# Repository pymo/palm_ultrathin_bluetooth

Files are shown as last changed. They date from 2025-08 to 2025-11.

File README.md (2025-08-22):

# Palm Ultra-thin Keyboard (P10900U) Bluetooth Mod

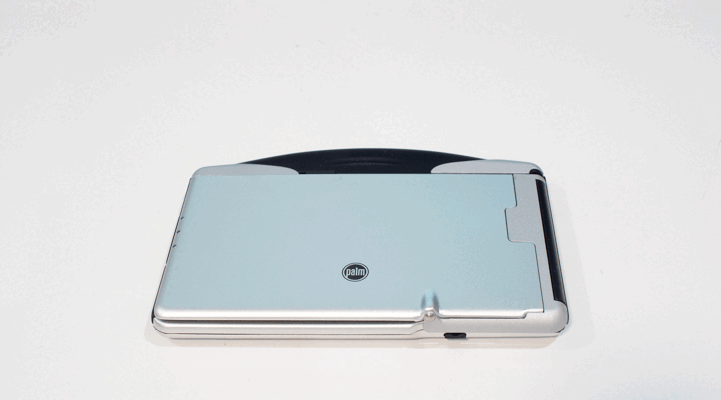
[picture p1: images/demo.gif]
Demo of Palm Ultra-thin keyboard


This project modifies the Palm Ultra-thin Keyboard into a Bluetooth keyboard. The conversion kit includes a custom PCB that replaces the original one, a li-po battery, and a 3D printed cover with power switch. The Bluetooth PCB supports BLE 5.3, can pair up to 4 hosts simultaneously, and supports wired USB Type-C connection.

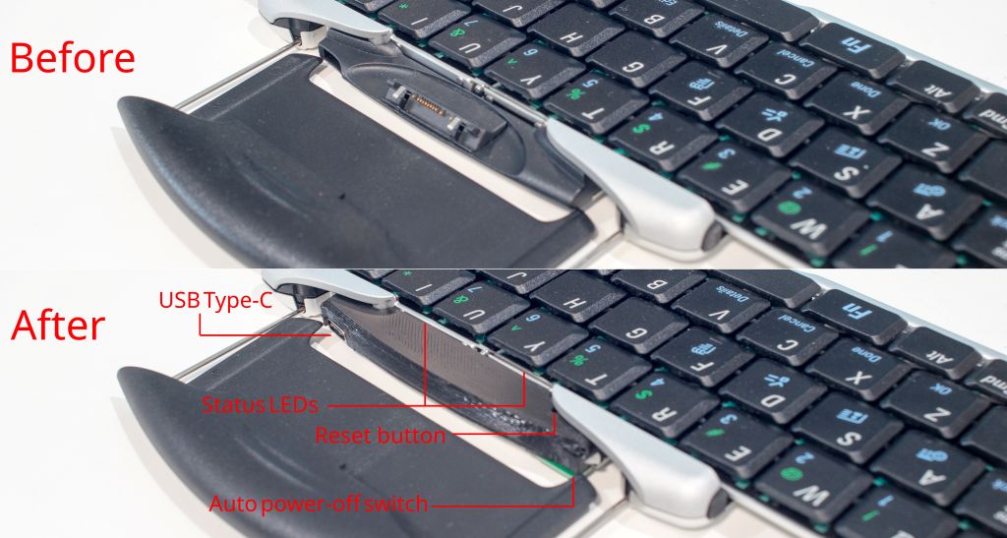
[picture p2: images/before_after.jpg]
Before and after the mod


Where to buy
-----------

You can buy the kit from my [Tindie store](https://www.tindie.com/products/39633/). You can also make the PCB by yourself if you are familiar with PCB making and SMT. The PCB files are in the `/pcb` folder.

Instructions to install the PCB
-----------

[Tutorial for installing the PCB into the keyboard](install.md)

Keyboard Matrix
-----------

[Keyboard matrix table](matrix.md).

PCB design and firmware
-----------
The PCB uses a WCH CH582F chip, a RISC-V based Bluetooth controller. It is low cost, power efficient and easy enough to use, which is why I chose it. The PCB files are at the /pcb folder.

The firmware is in the release page. Follow [this tutorial](https://github.com/pymo/wch_micro_kbd/blob/main/doc/wch_isp_tool.md) to flash the firmware. The source code is in a [separate repo](https://github.com/pymo/wch_micro_kbd/).

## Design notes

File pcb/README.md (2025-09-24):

# Other components used

- switch:  model No. KFC-V-204F or MS-V-204F.
- switch and battery connector: SH 1.0 2-pin
- battery: 401225 Li-Po battery 130mAh (4mm x 12mm x 25mm in dimensions).

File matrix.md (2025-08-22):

# Palm Ultra-thin Keyboard matrix

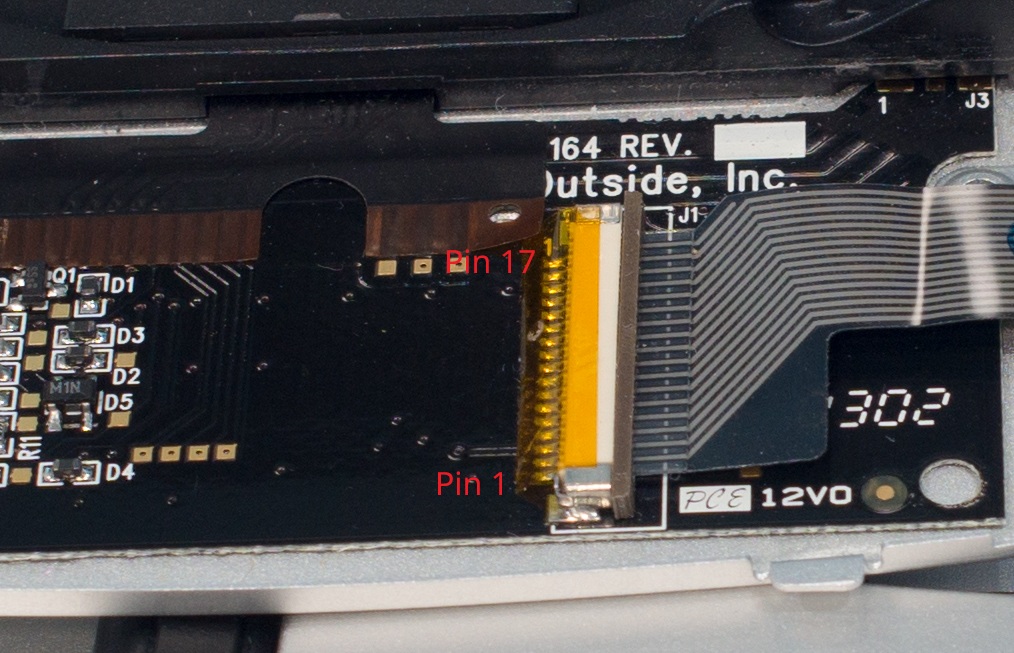
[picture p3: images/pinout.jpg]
Connector pinout


Pin 17 is not used.

| Pin No. | 3 | 4 | 9 | 10 | 14 |
| :---: | :---: | :---: | :---: | :---: | :---: |
| 1 | Up | M | U | Down | K |
| 2 | Left | N | Right Fn | Right Space | J |
| 5 | Return | BS | P | / | = |
| 6 | . | ' | O | Del | - |
| 7 | , | ; | I | Right | L |
| 8 |  |  |  | Right Shift | |
| 11 | V | B | F | C | Left Alt |
| 12 | Caps Lock | Left Ctrl | D | X | T |
| 13 | H | G | Left Fn | Left Space | Y |
| 15 | Q | W | A | Left Shift | E |
| 16 | Cmd | Tab | S | Z | R |

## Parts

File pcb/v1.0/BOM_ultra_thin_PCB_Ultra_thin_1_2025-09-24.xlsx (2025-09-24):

No. | Quantity | Comment | Designator | Footprint | Value | Manufacturer Part | Manufacturer | Supplier Part | Supplier | JLCPCB Price | JLCPCB Stock
1 | 2 | YTC-A1001WF-02A | BATTERY_CONNECTOR,SWITCH_CONNECTOR | CONN-SMD_YTC-A1001WF-02A |  | YTC-A1001WF-02A | YIYUAN(怡远) | C7433423 | LCSC | 0.152 | 31643
2 | 1 | K2-1809SN-A4DW-06 | BOOT | KEY-SMD_4P-L3.5-W3.0-P1.50-LS4.6 |  | K2-1809SN-A4DW-06 | 韩国韩荣 | C223823 | LCSC | 0.657 | 2435
3 | 3 | 2.2uF | C1,C4,C8 | C0603 | 2.2uF | CL10A225KO8NNNC | SAMSUNG(三星) | C23630 | LCSC | 0.0397 | 1952639
4 | 2 | 100nF | C2,C11 | C0402 | 100nF | CL05B104KO5NNNC | SAMSUNG(三星) | C1525 | LCSC | 0.0076 | 11288985
5 | 2 | 1uF | C3,C7 | c0402 | 1uF | CL05A105KA5NQNC | SAMSUNG(三星) | C52923 | LCSC | 0.019 | 5187096
6 | 2 | 10uF | C9,C10 | C0603 | 10uF | CL10A106MA8NRNC | SAMSUNG(三星) | C96446 | LCSC | 0.12 | 2235026
7 | 1 | CH582F | CH582F | qfn-28_l4.0-w4.0-p0.40-bl-ep2.8 |  | CH582F | WCH(南京沁恒) | C3001175 | LCSC | 7.84 | 2060
8 | 1 | 1N5819WS | D2 | SOD-323_L1.8-W1.3-LS2.5-RD |  | 1N5819WS | Hottech(合科泰) | C191023 | LCSC | 0.0632 | 2884036
9 | 1 | ESDR0502NMUTBG | D3 | UDFN-6_L1.2-W1.0-P0.40-BL |  | ESDR0502NMUTBG | onsemi(安森美) | C327480 | LCSC | 1.087 | 2893
10 | 1 | X10B25L17T | FPC1 | FPC-SMD_X10B25U17T |  | X10B25L17T | XKB Connection(中国星坤) | C500176 | LCSC | 0.904 | 2042
11 | 1 | 22uH | L1 | IND-SMD_L2.0-W1.6_NR201610 | 22uH | YNR2016-220M | YJYCOIN(益嘉源) | C2858408 | LCSC | 0.382 | 2259
12 | 1 | LTST-C171TBKT | LED_BLUE | LED0805-RD_BLUE |  | LTST-C171TBKT | LITEON(光宝) | C98225 | LCSC | 0.145 | 28461
13 | 1 | KT-0805G | LED_GREEN | LED0805-R-RD |  | KT-0805G | KENTO | C2297 | LCSC | 0.0714 | 1329987
14 | 1 | NCD0805R1 | LED_RED | LED0805-R-RD |  | NCD0805R1 | 国星光电 | C84256 | LCSC | 0.0879 | 5070270
15 | 1 | KT-0805Y | LED_YELLOW | LED0805-R-RD |  | KT-0805Y | KENTO | C2296 | LCSC | 0.0835 | 266228
16 | 1 | AO3401A | Q2 | SOT-23_L2.9-W1.3-P1.90-LS2.4-BR |  | AO3401A | AOS | C15127 | LCSC | 0.385 | 2428201
17 | 5 | 5.1kΩ | R1,R2,R12,R27,R28 | R0402 | 5.1kΩ | 0402WGF5101TCE | UNI-ROYAL(厚声) | C25905 | LCSC | 0.0031 | 4872753
18 | 4 | 820Ω | R3,R14,R15,R18 | R0603 | 820Ω | 0603WAF8200T5E | UNI-ROYAL(厚声) | C23253 | LCSC | 0.0068 | 228711
19 | 6 | 1MΩ | R16,R19,R20,R21,R22,R23 | R0805 | 1MΩ | 0805W8F1004T5E | UNI-ROYAL(厚声) | C17514 | LCSC | 0.0123 | 593756
20 | 2 | 74HC138T | U1,U2 | TSSOP-16_L5.0-W4.4-P0.65-LS6.4-BL |  | 74HC138T | FM(富满) | C2906781 | LCSC | 0.551 | 1444
21 | 1 | ME6214C33M5G | U5 | SOT-23-5_L3.0-W1.7-P0.95-LS2.8-BL |  | ME6214C33M5G | MICRONE(南京微盟) | C76500 | LCSC | 0.516 | 28205
22 | 1 | TP4054-42-SOT25R | U7 | SOT-23-5_L3.0-W1.7-P0.95-LS2.8-BL |  | TP4054-42-SOT25R | TOPPOWER(南京拓微) | C32574 | LCSC | 0.853 | 8536
23 | 1 | TYPE-C 16PQT 073 | U11 | USB-SMD_TYPE-C-16PQT-073 |  | TYPE-C 16PQT 073 | SHOU HAN(首韩) | C5156603 | LCSC | 0.541 | 3691
24 | 1 | 32MHz | X1 | OSC-SMD_4P-L2.0-W1.6-BL | 32MHz | X201632MMB4SI | YXC(扬兴晶振) | C383840 | LCSC | 0.649 | 2369

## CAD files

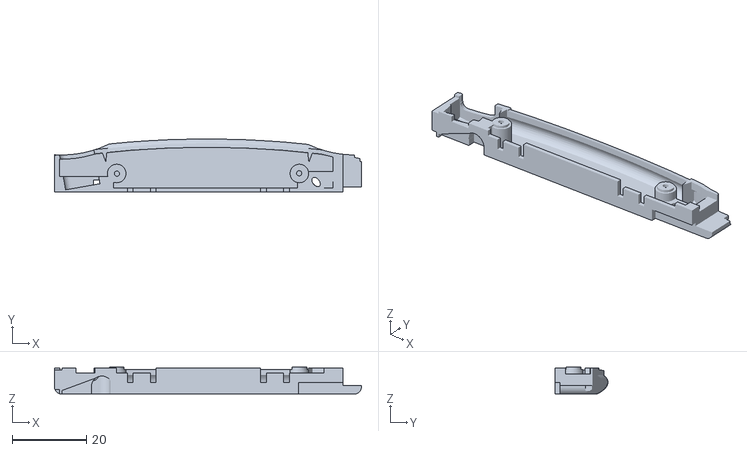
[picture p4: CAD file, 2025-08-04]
3d_print/cover.stl
82.7 x 14.3 x 7.20

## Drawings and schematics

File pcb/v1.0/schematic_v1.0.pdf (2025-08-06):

# 图页EP 29

# PB22/BOOT GND

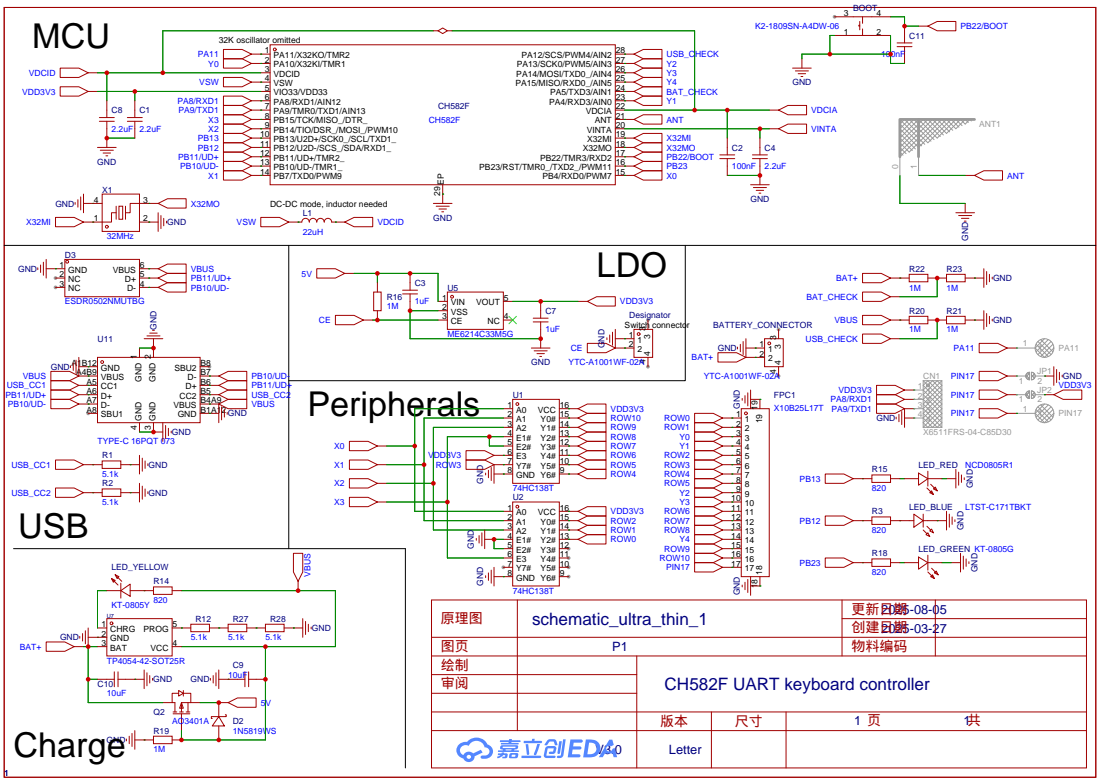
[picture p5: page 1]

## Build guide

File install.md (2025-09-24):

# How to install the Bluetooth conversion kit for Palm Ultra-thin Keyboard

Unscrew the 4 screws at the back of the keyboard.

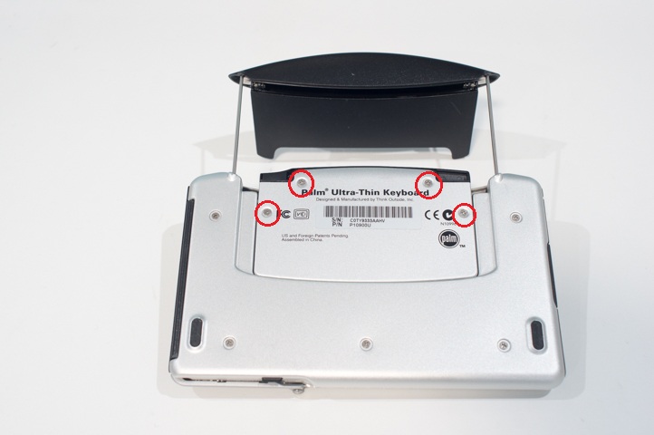
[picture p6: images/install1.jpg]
install pic


Flip the back cover, release the FPC cable by pulling out the "drawer" of the connector.

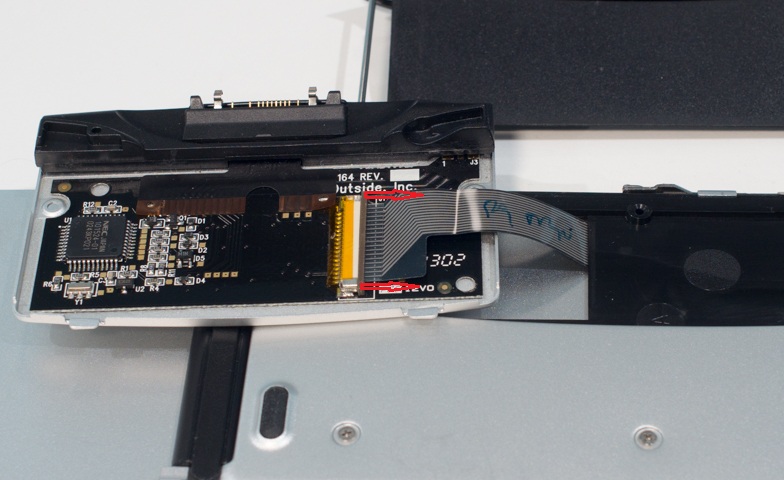
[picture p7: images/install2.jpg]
install pic


Use a prying tool to pry between the PCB and the metal back cover, start from the top left corner. Be careful not to cut yourself with the sharp edges of the tool or the back cover. Be careful not to bend the back cover.

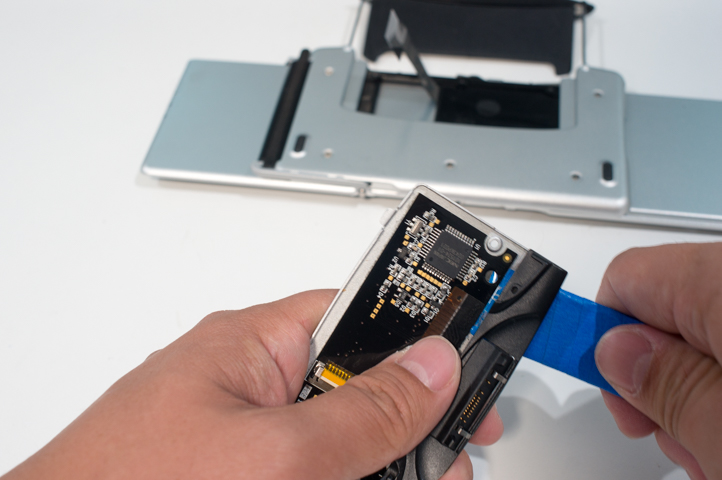
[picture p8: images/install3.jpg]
install pic


Once the PCB comes off, peel any remaining double sided tape off the back cover. If there are any adhesive remaining, it's fine, it can help the new PCB to stick to the back cover.

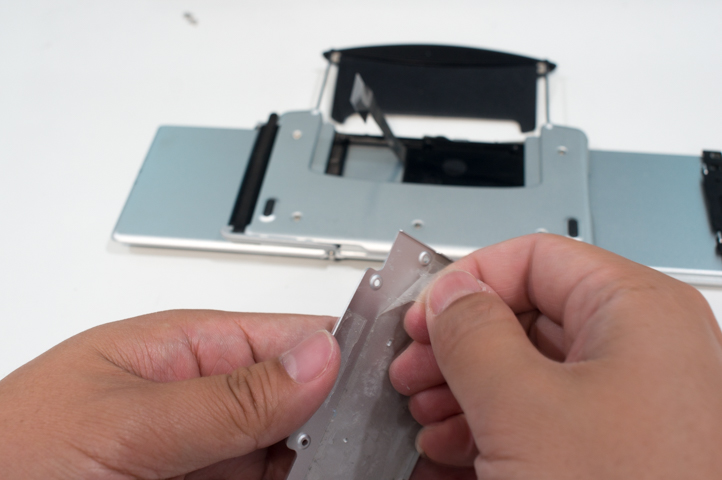
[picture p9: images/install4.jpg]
install pic


Put the new PCB on the back cover. Try to align the screw holes as well as possible.

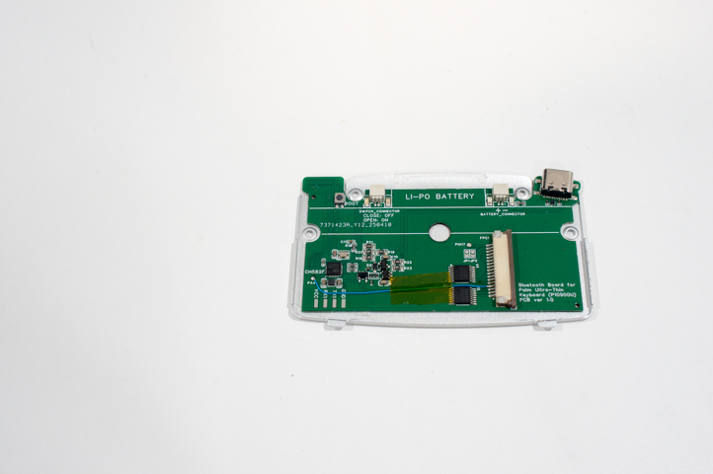
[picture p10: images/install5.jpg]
install pic


Plug in the battery and the power switch, make sure the polarity is correct! The positive (red wire) should be on the left side when looking from top, as marked on the PCB too.

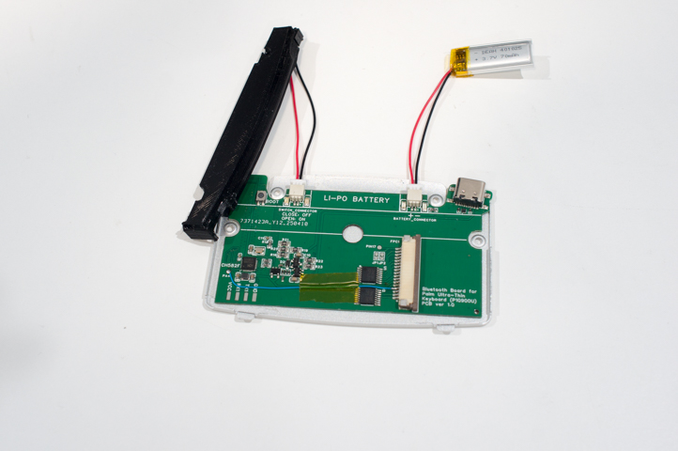
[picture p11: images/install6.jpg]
install pic


Use double sided tape to tape the battery into place, and tuck the wires on the battery.

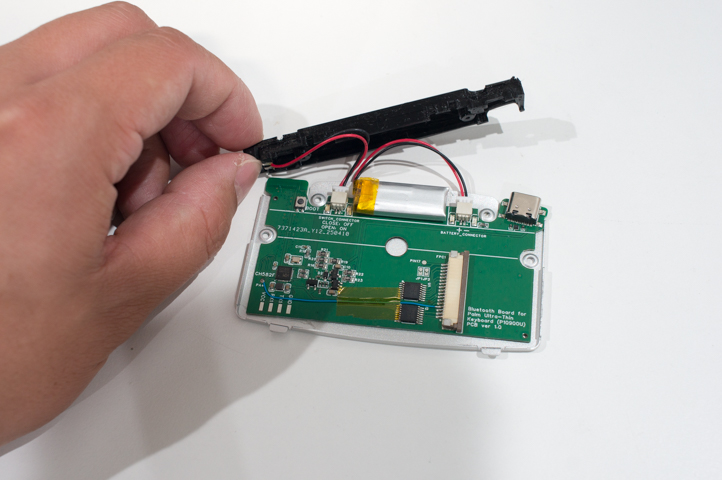
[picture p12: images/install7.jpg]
install pic


Place the 3-D printed cover on the battery. The wires should be tucked inside the cover.

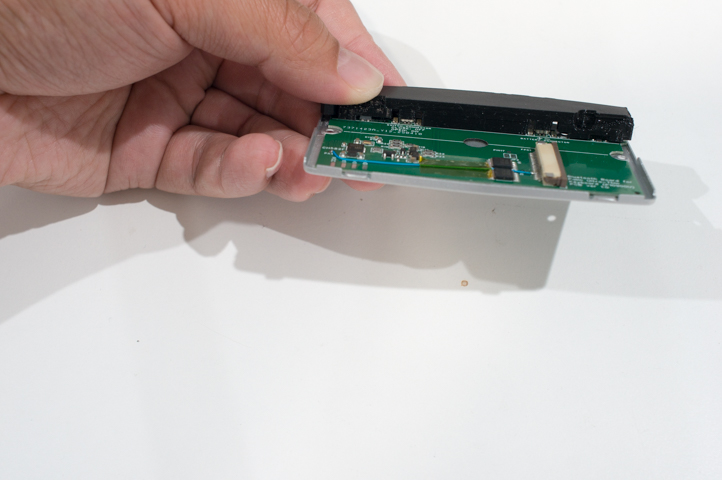
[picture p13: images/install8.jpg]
install pic


Use the two shorter screws to fasten the back cover with the 3-D printed cover.

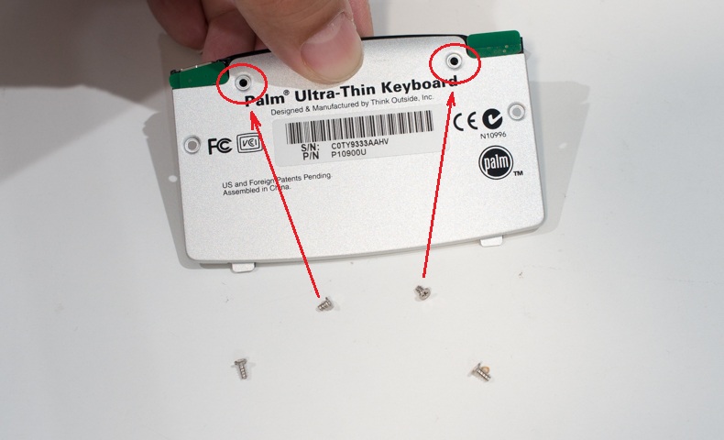
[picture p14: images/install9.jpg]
install pic


Insert the FPC cable fully to the new socket, close the "drawer" part to secure the connection.

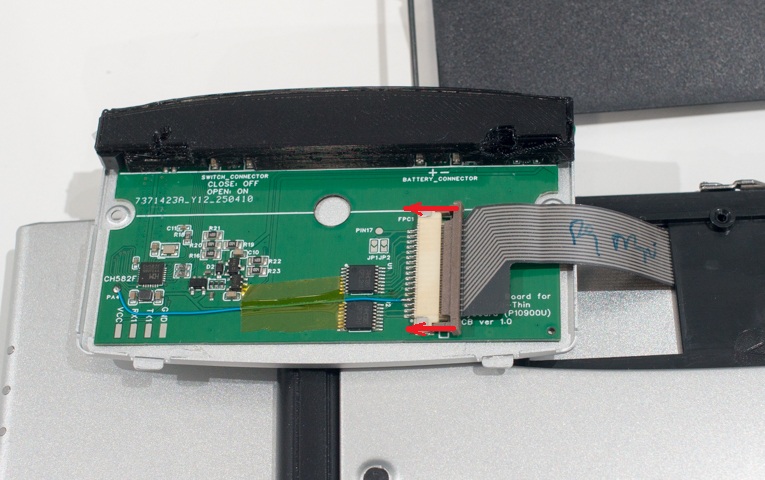
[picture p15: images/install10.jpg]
install pic


Screw the two longer screws to fasten the back cover onto the keyboard.

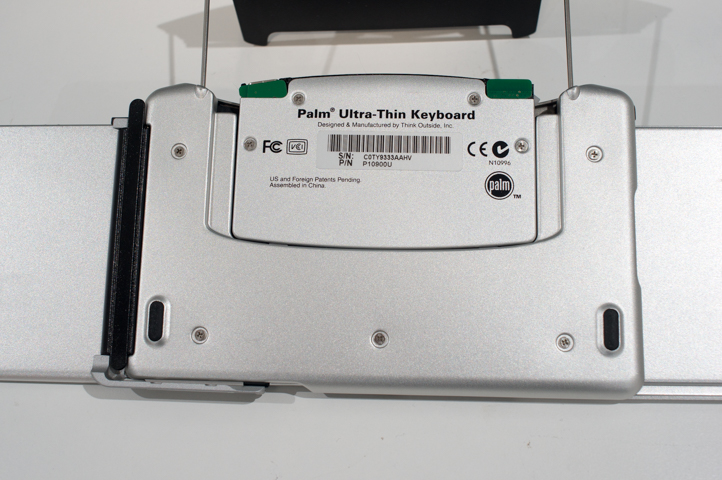
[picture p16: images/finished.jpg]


Safety warnings
---------------------
- The prying tool can have some rough edges, it is recommended to wear some protective gloves when prying the PCB, to avoid cuts to your hand. Or wrap the tool with some painter's tape.
- As with any device using Li-Po battery, don't dismantle or damage the battery. Don't discharge the battery to a very low state. Please charge the battery as soon as you see the red LED blinks to ensure the longevity of the battery.

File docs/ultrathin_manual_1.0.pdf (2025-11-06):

# Palm Ultra-thin Keyboard Bluetooth Manual

https://github.com/pymo/palm_ultrathin_bluetooth | hardware rev. 1.0 2025-08-20
To open the keyboard: | To fold the keyboard:

How to install:
- Please refer to https://github.com/pymo/palm_ultrathin_bluetooth/blob/main/install.md

How to use:
- Open the keyboard, and pull out the kick-stand, the adapter automatically powers on. Search it on your phone or PC’s Bluetooth settings, it shows up as “PDA Keyboard 1”. Pair it and it will work.
- The adapter supports pairing up to 4 Bluetooth hosts simultaneously, and supports wired USB connection, too.
- Press Left Fn+A, S, D or F to switch between Bluetooth hosts 1~4, the Bluetooth name is "PDA Keyboard 1/2/3/4", respectively.
- Long press Left Fn+A, S, D or F for 1 second to force that "channel" into pairing mode again.
- Press Left Fn+B to switch to USB mode (it does not automatically switch to USB mode when USB cable is plugged in, the user has to manually switch it)
- If the adapter's LED does not blink when opened, the battery may be depleted, charge it up using a USB type-C cable (not included)
- To factory reset the adapter, use a pin or a paper clip to press and hold the small hole on the adapter for 3 seconds. Do this if you have pairing issues. You also need to "forget" the keyboard in the host's settings before pairing again.

LED Functionality:
- Yellow LED: charging indicator
- On: charging.
- Off: charge complete.
- Blue LED: Bluetooth indicator
- Blue and Red alternately blink: Bluetooth pairing mode.
- Fast blink: reconnecting to the last paired host.

Slide tab to right to
release and close
keyboard

- Slow blink 1/2/3/4 times: Paired to the host 1/2/3/4, normal usage. The blink will stop after 30 seconds to avoid distraction.
- Constant on: USB mode. The LED will turn off after 30 seconds to avoid distraction.
- Off: the keyboard is in sleep, or it has been more than 30 seconds since the last mode switch.
- Green LED: Caps Lock indicator
- On: Caps Lock on.
- Off: Caps Lock off.
- Red LED: battery indicator
- blink once: battery is below 20%.
- blink twice: battery is below 15%.
- blink three times: battery is below 10%.

Special Keyboard Shortcuts:
Keystroke Combination | Function
Left Fn + A, S, D, F | Bluetooth host switch.
Left Fn + A, S, D, F (long press 1 second) | Enter pairing mode for this host.
Left Fn + B | USB mode
Left Fn + Right Fn + Q, W, E, ... -, = | F1, F2, F3, ... F11, F12

Cmd

Left Fn + Tab | Esc
Left Fn + del | Insert
Left Fn + Cmd | iOS Home
Left Fn + ↑ or ↓ | Volumn Down / Up
Left Fn + ← or → | Brightness Down / Up
Left Fn + < or > | Previous/Next Song
Left Fn + Space | Play / Pause
Left Fn + K | Menu
Left Fn + L | PrintScreen

Safety Warnings:
This device contains a Lithium-Polymer battery.
- Please do not crush, disassemble or puncture the device; There is a risk of fire by doing so.
- Please recharge as soon as the Red LED starts blinking, to maintain the longevity of the battery.
- If this device is not used for a long time, please charge it at least every 3 months.

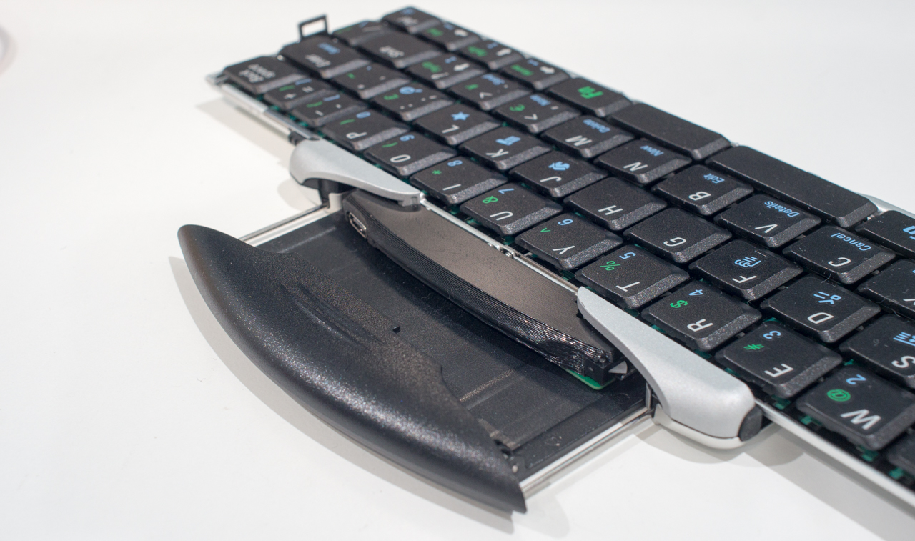
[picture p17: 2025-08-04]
images/manual.jpg

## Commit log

2025-08-04 Adds PCB photo and 3d print file
    [cover.stl]
2025-08-06 Adds PCB files
2025-09-24 Adds BOM and SMT files
    [BOM_ultra_thin_PCB_Ultra_thin_1_2025-09-24.xlsx, PickAndPlace_PCB_Ultra_thin_1_2025-09-24.xlsx]
